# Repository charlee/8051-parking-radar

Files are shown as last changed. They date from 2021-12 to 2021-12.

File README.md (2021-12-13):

Parking Radar
==============

This is a "parking radar" that can be installed on the wall of your garage.
When parking in the garage, it will show the distance between your car and the wall,
preventing you from accidentally crashing into the wall.

## Hardware

The hardware consists of the following parts:

- A 40pin through-hole MCS51 MCU (AT89C52 used in this project)
- A 6MHz crystal
- Ultrasonic module: HC-SR04
- A 3-digit seven segment display
- 3 3mm LEDs, red/yellow/green
- Resistors:
  - 680Ω x 11
  - 10kΩ x 2
  - 5kΩ x 3
- Capacitors:
  - 22pF ceramic capators x 2
  - 100nF (104) ceramic capator x 1
  - 10μF electrolytic capator x 1
- NPN Transistors (any type, S9012 used in this project) x 3
- A Schottky diode (1N5819 used here)
- A DC connector
- A 7cm x 10cm single-sided perfboard

## Schematic

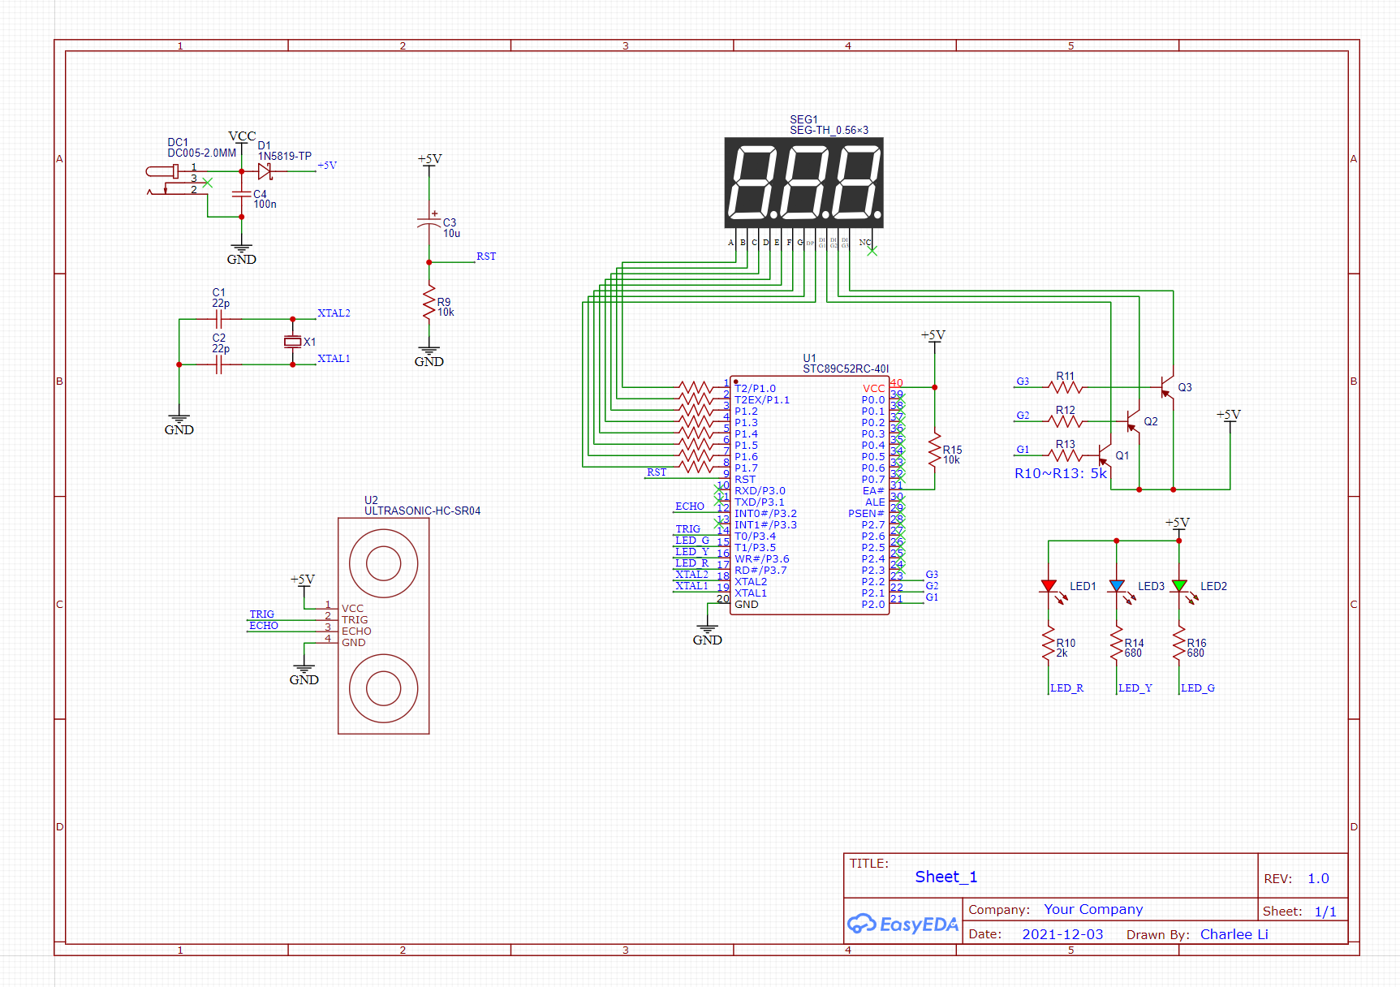
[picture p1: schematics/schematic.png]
Schematic


## Software

The program is written in C and is compiled with [SDCC](http://sdcc.sourceforge.net/).
Tested under Windows 10.  Run the following command to build:

```
> cd src
> make
```

If you need `make` command, please install it with [chololatey](https://chocolatey.org/):

```
(Adminstrator) > chocolatey install make
```

Download the generated `parking-radar.hex` to your MCS51 MCU.

## Case

The case is 3D printed. You can find the STL files and the Sketchup source file in the [3dmodels](3dmodels) directory.

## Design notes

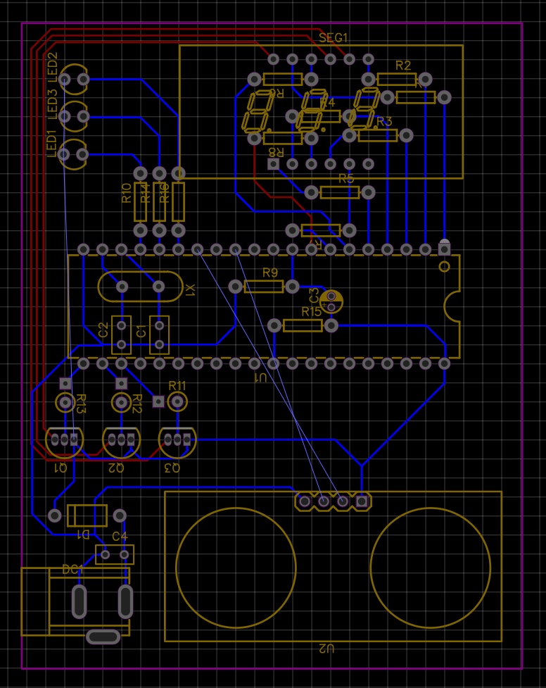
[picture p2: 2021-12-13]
schematics/pcb.png

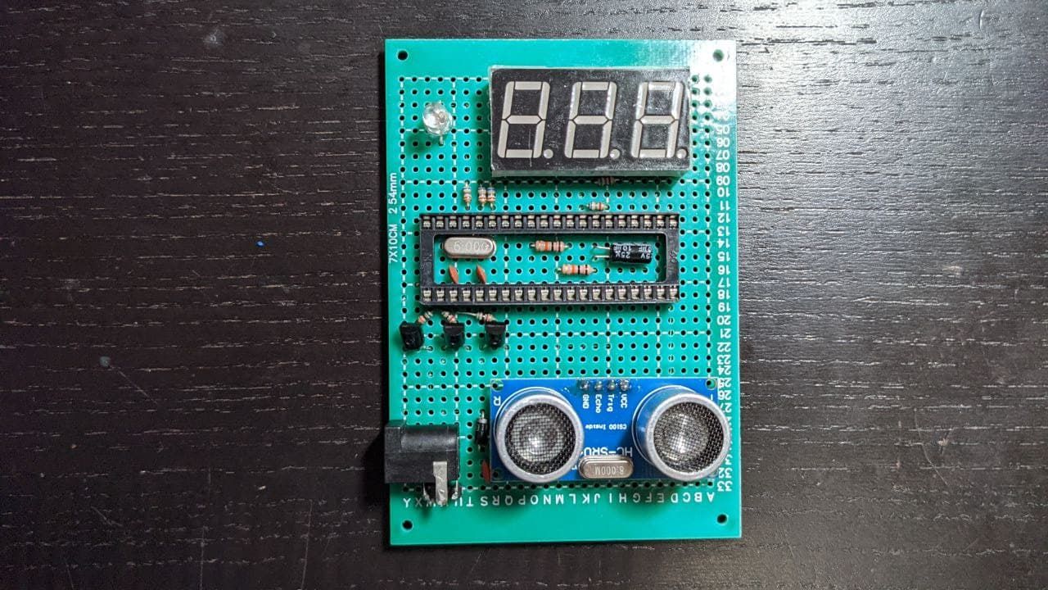
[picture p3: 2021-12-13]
gallery/03-pcb.jpg

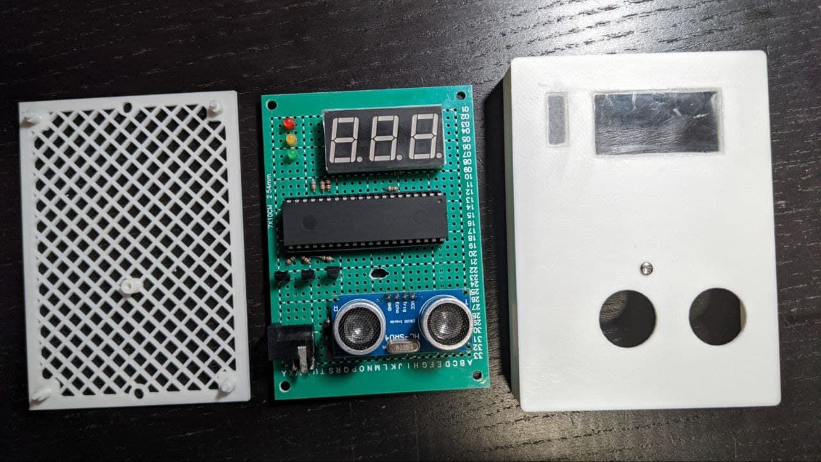
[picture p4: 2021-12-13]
gallery/05-pcb-with-case.jpg

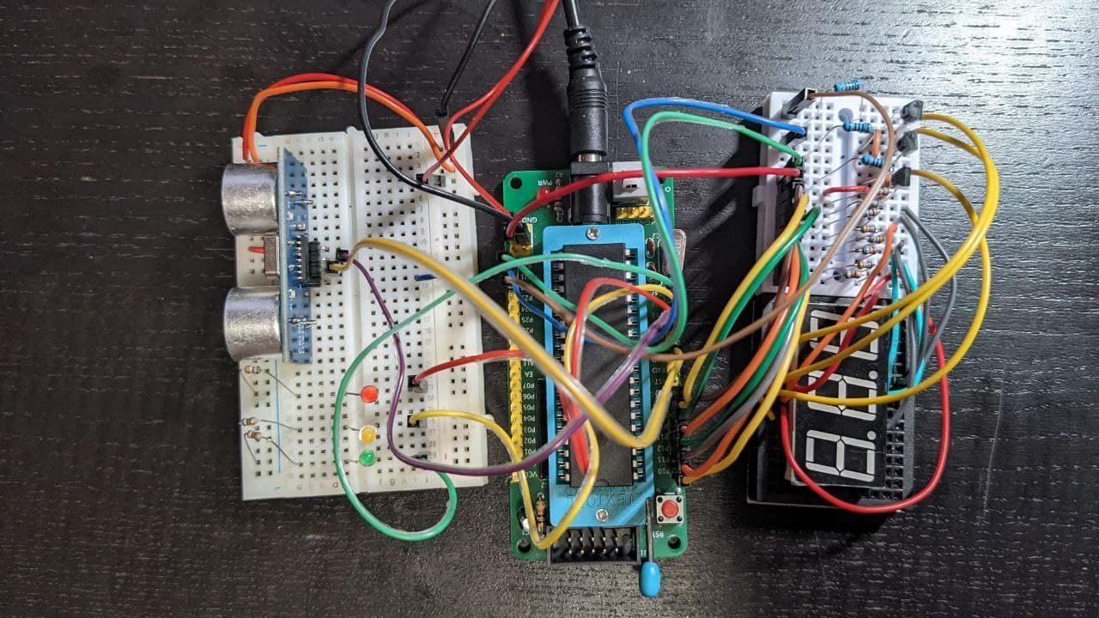
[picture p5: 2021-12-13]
gallery/01-breadboard.jpg

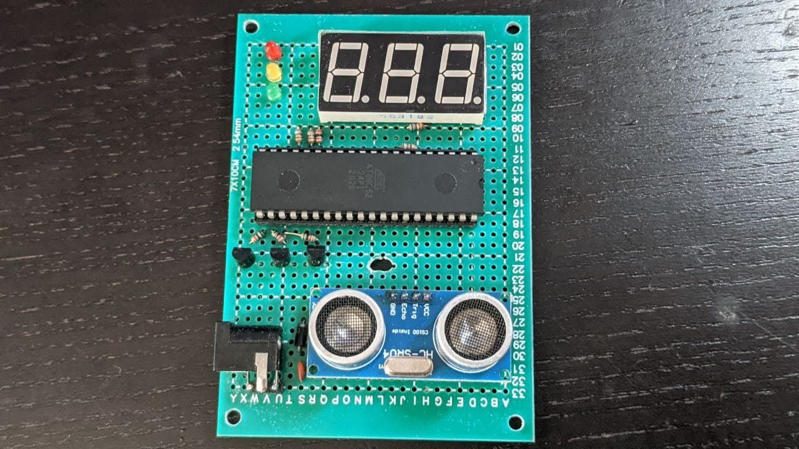
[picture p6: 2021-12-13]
gallery/04-pcb-with-mcu.jpg

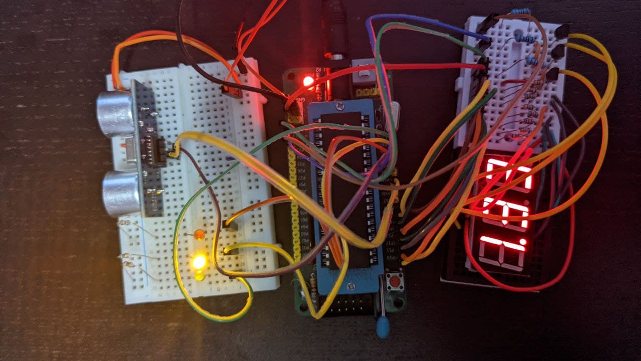
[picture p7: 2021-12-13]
gallery/02-breadboard-running.jpg

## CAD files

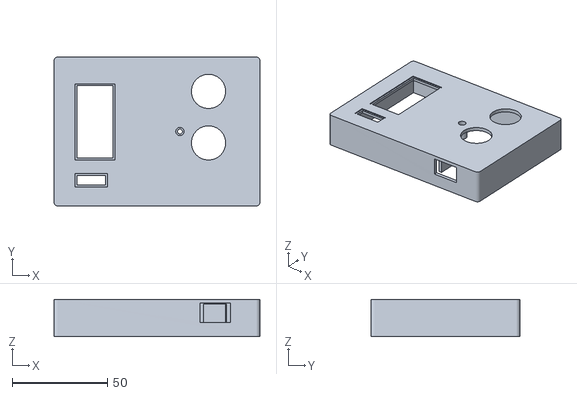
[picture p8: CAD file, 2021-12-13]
3dmodels/parking-radar-case-cover.stl
108.0 x 78.0 x 19.5

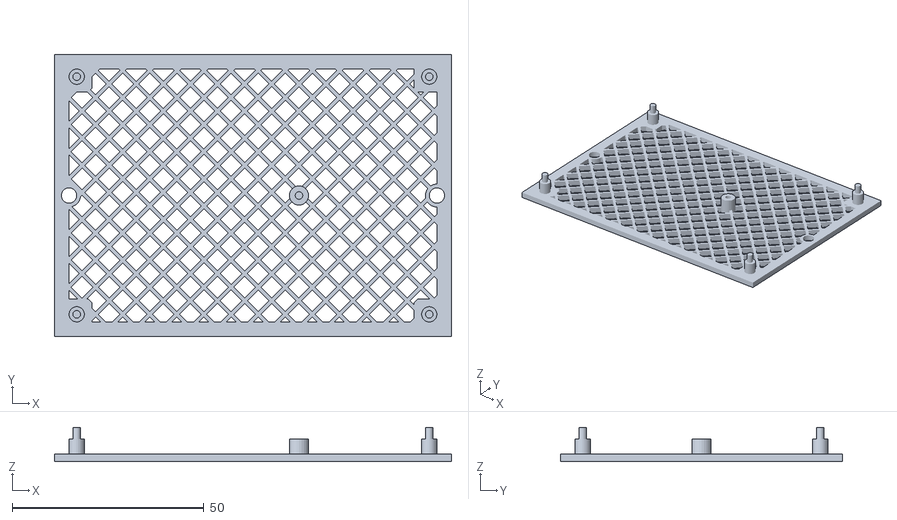
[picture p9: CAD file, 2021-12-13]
3dmodels/parking-radar-case-base.stl
103.6 x 73.6 x 9.00

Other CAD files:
3dmodels/parking-radar-case.skp

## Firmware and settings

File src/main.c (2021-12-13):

#include <8052.h>


#define LED_R P3_5
#define LED_Y P3_6
#define LED_G P3_7

#define TRIG P3_4

#define SEGS P1
#define GROUP P2


// #define T0_INTERVAL 12000
// #define reset_T0() { TL0 = (65536 - T0_INTERVAL) % 256; TH0 = (65536 - T0_INTERVAL) / 256; }
#define reset_T0() { TL0 = 0; TH0 = 0; }


// 4ms
// use a prime number to prevent flickering when ET1 is off
#define T1_INTERVAL 2003
#define reset_T1() { TL1 = (65536 - T1_INTERVAL) % 256; TH1 = (65536 - T1_INTERVAL) / 256; }

#define FAR 1
#define NEAR 0



__code unsigned char sevenseg_hex[] = {
  0x3F, 0x06, 0x5B,  0x4F,
  0x66, 0x6D, 0x7D, 0x07,
  0x7F, 0x6F, 0x77, 0x7C,
  0x39, 0x5E, 0x79, 0x71
};


// distance in centimeter, maximum 400 (HC-SR01 limit)
unsigned int distance = 400;

// used for debouncing distance change
unsigned int prev_dist_type = FAR;
unsigned int dist_type_change_counter = 0;

unsigned char digits[4];

// display on/off flag
unsigned char display_on = 0;


void show() {
  ET1 = 0;
  digits[2] = distance % 10;
  digits[1] = (distance / 10) % 10;
  digits[0] = distance / 100;
  ET1 = 1;
}

unsigned char get_distance_type(unsigned int dist) {
  if (dist > 120) {
    return FAR;
  } else {
    return NEAR;
  }
}

void set_leds() {
  unsigned char dist_type = get_distance_type(distance);
  // turn of everything if further than 2 meters
  if (distance > 200) {
    LED_R = 1;
    LED_Y = 1;
    LED_G = 1;
    GROUP = 0xff;
    SEGS = 0xff;

    display_on = 0;

  } else {

    display_on = 1;

    if (distance > 120) {
      LED_R = 1;
      LED_Y = 1;
      LED_G = 0;
    } else if (distance > 90) {
      LED_R = 1;
      LED_Y = 0;
      LED_G = 1;
    } else {
      LED_R = 0;
      LED_Y = 1;
      LED_G = 1;
    }
  }
}


void init() {
  // Turn off all digits
  GROUP = 0xff;
  SEGS = 0xff;

  // Turn off LEDs
  LED_G = 1;
  LED_R = 1;
  LED_Y = 1;

  TRIG = 0;

  // setup timer 0 and timer 1
  TMOD = 0x11;

  EA = 1;
  ET0 = 1;    // enable timer0
  ET1 = 1;    // enable timer1
  TCON = 0x01;  // set both INT0 and INT1 to trigger on falling edge

  // Start timer 1
  TR1 = 1;
}

void delay(int n){
  while (n--);
}

void start_detect_distance() {

  // reset T0 before sending signal to avoid extra cycles caused by the assignment
  reset_T0();

  // disable display timer (timer1) to make sure timing is correct.
  // ET1 = 0;
  TRIG = 1;
  __asm
  nop
  nop
  nop
  nop
  nop
  __endasm;
  TRIG = 0;
  // ET1 = 1;

  EX0 = 1;
  TR0 = 1;    // start timer1 for timeout
}



void main() {

  init();

  while(1) {
    show();
    set_leds();
    delay(30000);
    start_detect_distance();
  }

}

/**
 * Ultrasound sensor echo input
 */
void echo_stop_trigger() __interrupt 0 {
  unsigned int measure;
  unsigned char measure_type;

  // echo triggered, stop timer0 and output distance
  EX0 = 0;
  TR0 = 0;

  measure = (TH0 * 256 + TL0) / 29;
  measure_type = get_distance_type(measure);

  if (measure_type == prev_dist_type) {
    ET1 = 0;
    distance = measure;
    ET1 = 1;
  } else if (dist_type_change_counter >= 2) {
    ET1 = 0;
    distance = measure;
    ET1 = 1;
    prev_dist_type = measure_type;
    dist_type_change_counter = 0;
  } else {
    dist_type_change_counter++;
  }
}

/**
 * timer0 is used to time the ultrasonic echo.
 */
void timer0() __interrupt 1 {
  EX0 = 0;
  TR0 = 0;
}


unsigned char scan_pos = 0;

/**
 * timer1 is used to handle the 7seg scanning.
 */
void timer1() __interrupt 3 {

  if (!display_on) return;

  SEGS = 0xff;

  // GROUP connections are G3=P3.0, G2=P3.2, G1=P3.4
  GROUP = ~(0x01 << scan_pos);

  if (scan_pos == 0) {
    // show blinking dot
    SEGS = ~(sevenseg_hex[digits[scan_pos]] | 0x80);
  } else {
    SEGS = ~sevenseg_hex[digits[scan_pos]];
  }

  scan_pos++;
  if (scan_pos == 3) {
    scan_pos = 0;
  }

  reset_T1();
}

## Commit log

2021-12-13 added readme
    [parking-radar-case-base.stl, parking-radar-case-cover.stl, parking-radar-case.skp]
2021-12-13 fixed some display issue
    [main.c]
